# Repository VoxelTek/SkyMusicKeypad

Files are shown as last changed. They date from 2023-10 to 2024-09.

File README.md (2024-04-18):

# Sky Music Keypad
 
A 5x3 grid of MX switches connected to an RP2040-Zero, intended for playing music in the same style as seen in [Sky: Children Of The Light](https://www.thatskygame.com/).



This project was initially created as a birthday present for a friend, but I realised that the community might appreciate this project, and may be able to improve on it in ways I never could.

This device supports MIDI output, keyboard emulation for [Sky Music Nightly](https://specy.github.io/skyMusic), and keyboard emulation for the PC port of Sky.

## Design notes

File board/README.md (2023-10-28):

# SkyMusicPad

A PCB design for a physical replication of the Sky music pad, from Sky: Children Of The Light. 

It uses mechanical keyboard switches for each note, set-up in a matrix arrangement, hooked up to an RP2040-Zero running CircuitPython. MIDI data is outputted over USB to a computer.

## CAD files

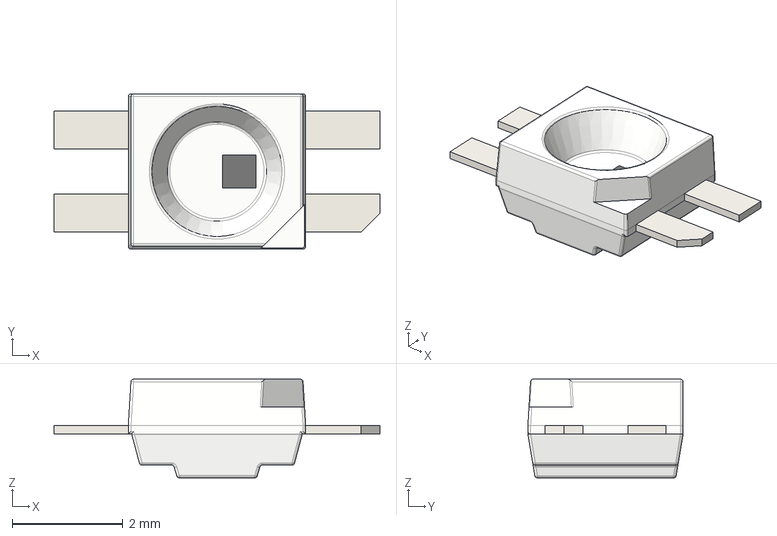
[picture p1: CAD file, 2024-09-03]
board/3D/LED_SK6812MINI-E.step
5.88 x 2.80 x 1.78 mm

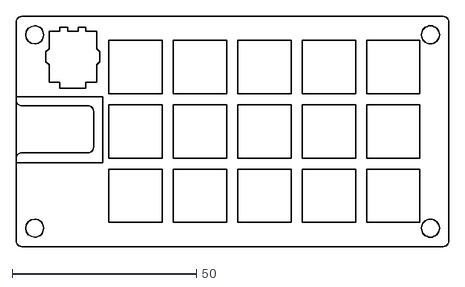
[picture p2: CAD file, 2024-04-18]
board/Outline/SkyMusicPad-brd.dxf
117.5 x 62.5

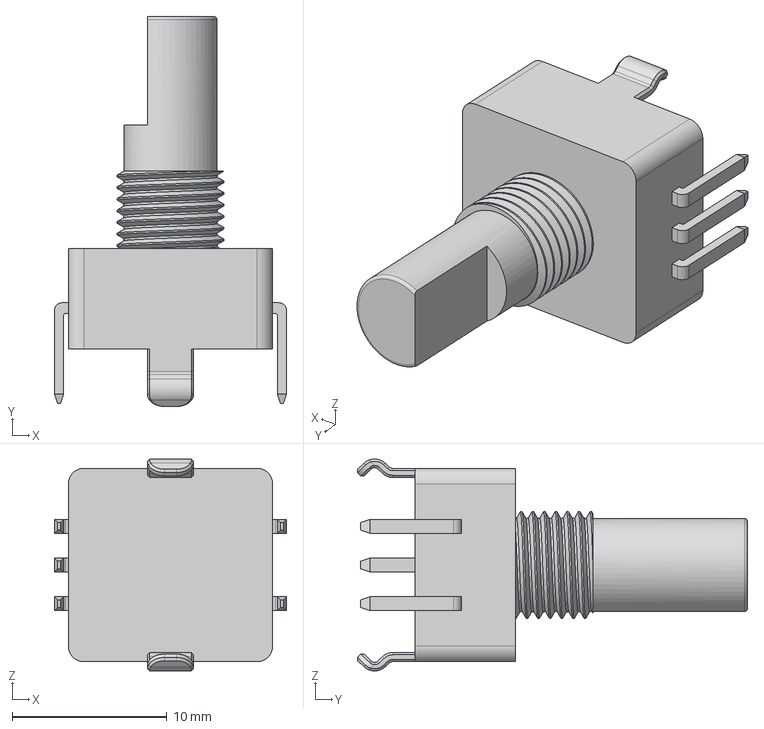
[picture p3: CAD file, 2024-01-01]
board/3D/Rotary Encoder.step
15.0 x 25.2 x 13.7 mm

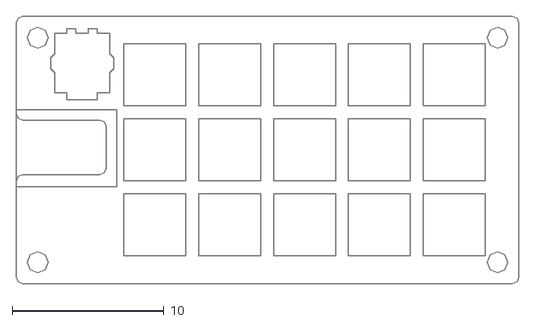
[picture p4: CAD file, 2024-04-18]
board/Outline/SkyMusicPad-brd_2.dxf
33.2 x 17.6

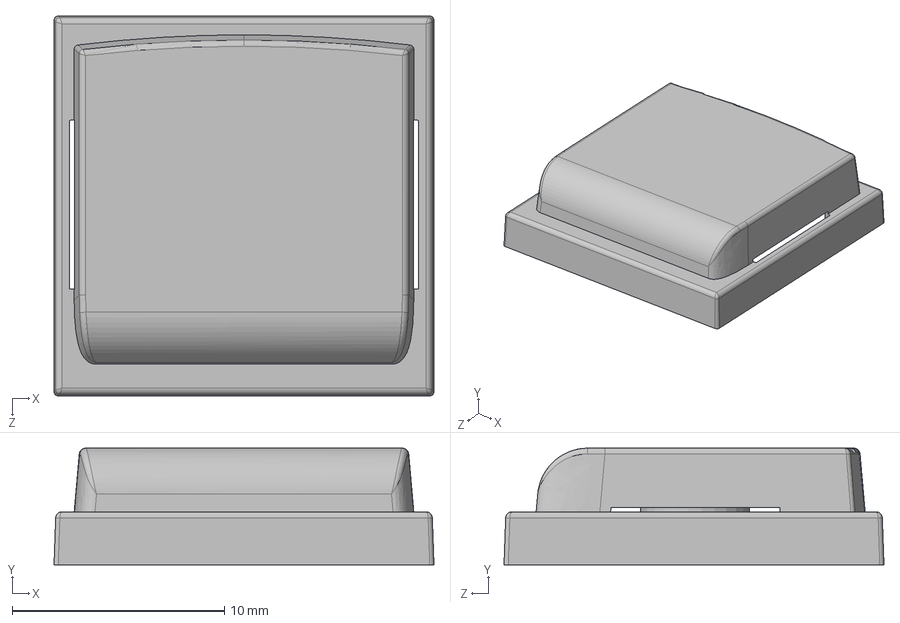
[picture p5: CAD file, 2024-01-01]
board/3D/Key Cap-CHERRY-MX.STEP
17.9 x 5.50 x 17.9 mm

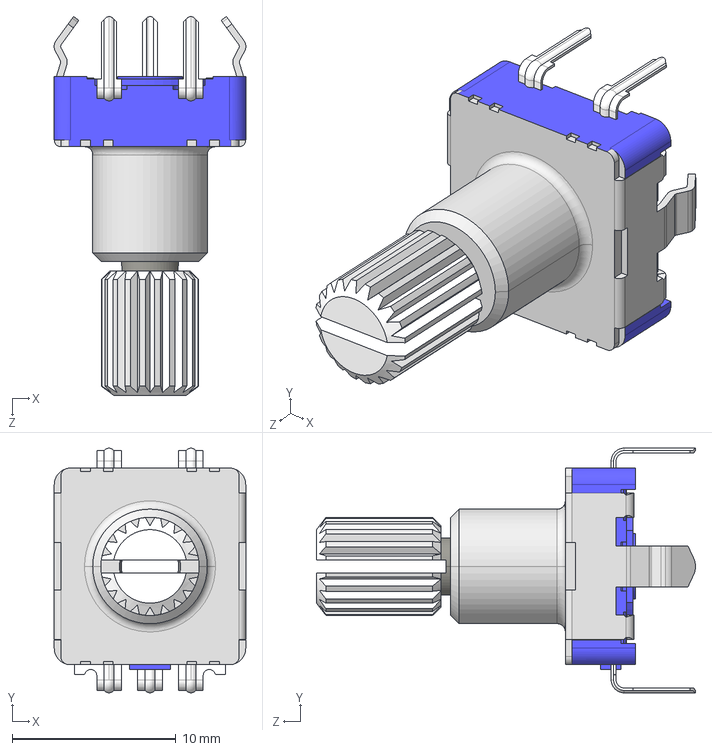
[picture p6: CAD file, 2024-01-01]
board/3D/EC11 Rotary Encoder Dode Switch-15mm .STEP
11.7 x 15.0 x 23.2 mm

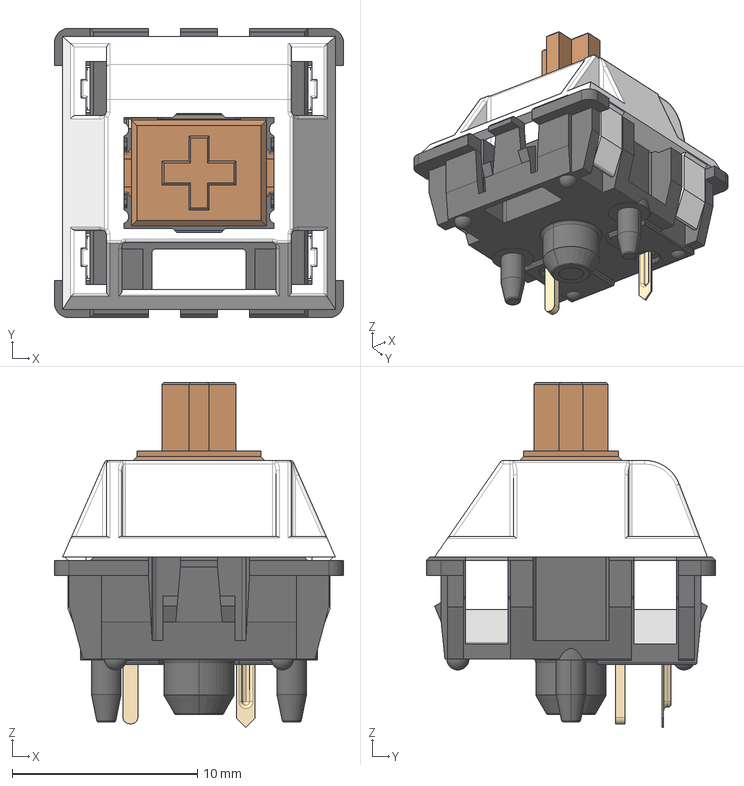
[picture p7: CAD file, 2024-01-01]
board/3D/SW_Cherry_MX_PCB.stp
15.6 x 15.6 x 18.6 mm

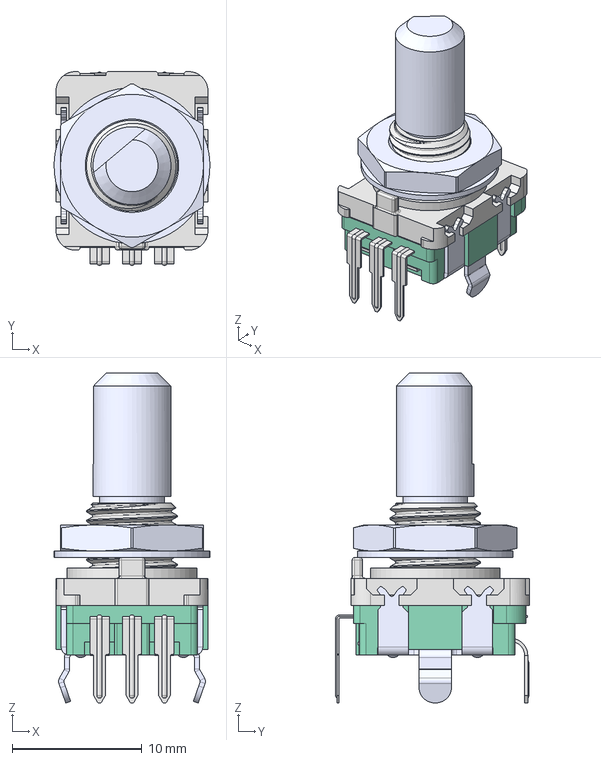
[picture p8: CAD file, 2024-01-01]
board/3D/EC11B-SW-Vert-15F-green.step
12.0 x 14.9 x 25.4 mm

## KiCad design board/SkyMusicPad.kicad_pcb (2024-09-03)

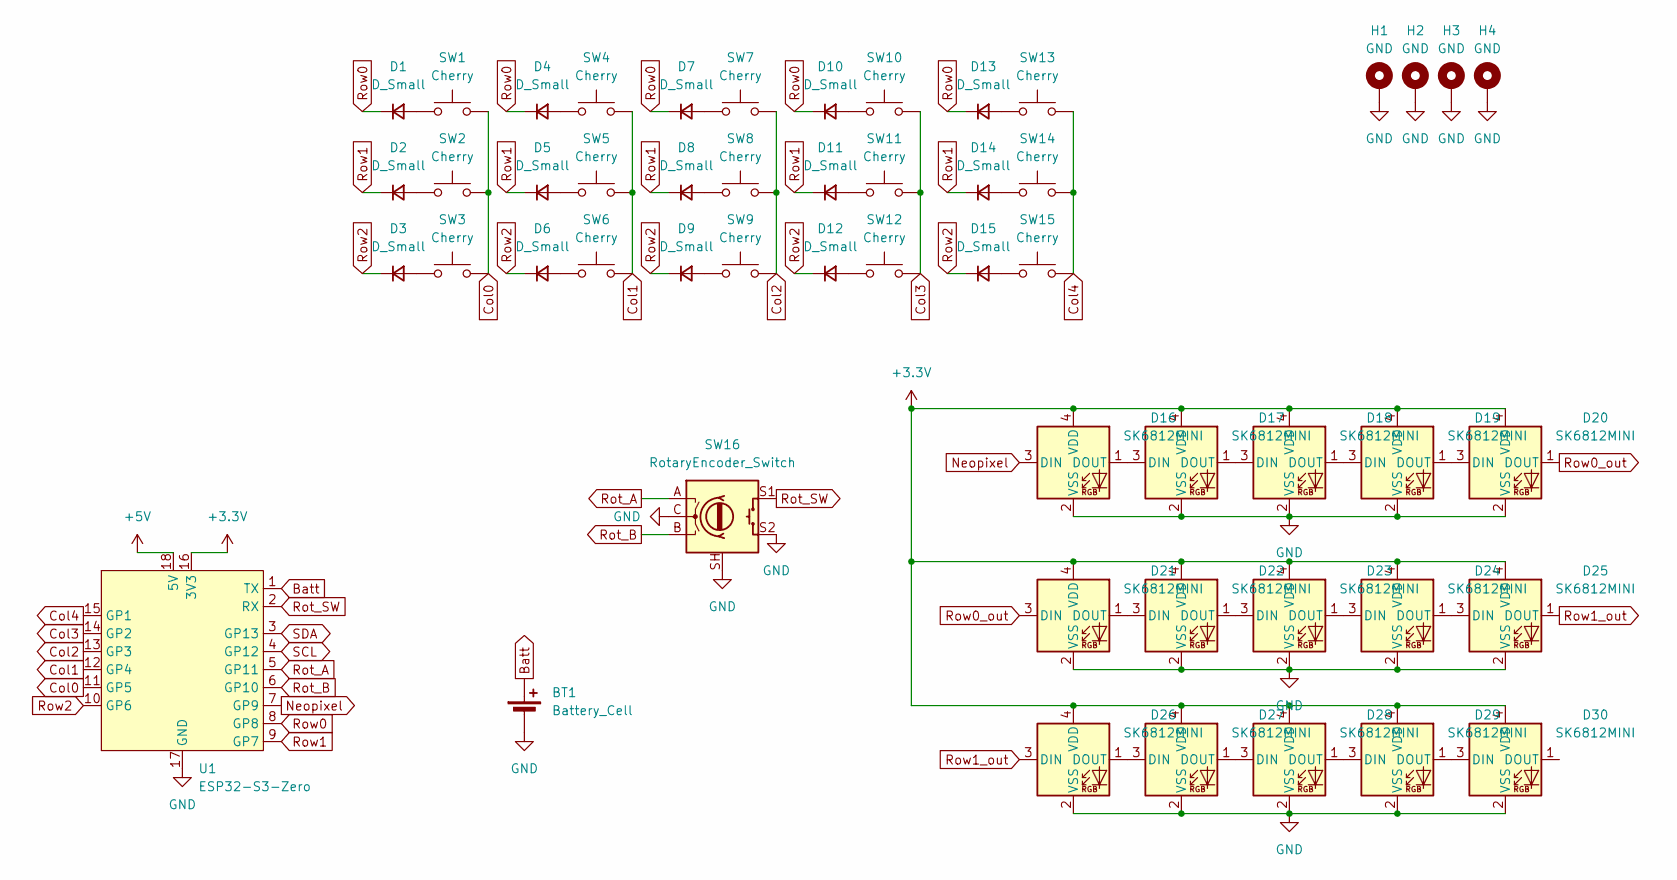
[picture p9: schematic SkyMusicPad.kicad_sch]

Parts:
BT1: Battery_Cell
D1, D2, D3, D4, D5, D6, D7, D8, D9, D10, D11, D12, D13, D14, D15: D_Small; D_0805_2012Metric
D16, D17, D18, D19, D20, D21, D22, D23, D24, D25, D26, D27, D28, D29, D30: SK6812MINI; LED_SK6812MINI_REVERSE
H1, H2, H3, H4: GND; MountingHole_2.2mm_M2_Pad_Via
SW1, SW2, SW3, SW4, SW5, SW6, SW7, SW8, SW9, SW10, SW11, SW12, SW13, SW14, SW15: Cherry; SW_Cherry_MX_PCB
SW16: RotaryEncoder_Switch; RotaryEncoder_Bourns_Vertical_PEC12R-3x17F-Sxxxx
U1: ESP32-S3-Zero

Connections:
+3.3V: D16.4 (VDD), D17.4 (VDD), D18.4 (VDD), D19.4 (VDD), D20.4 (VDD), D21.4 (VDD), D22.4 (VDD), D23.4 (VDD), D24.4 (VDD), D25.4 (VDD), D26.4 (VDD), D27.4 (VDD), D28.4 (VDD), D29.4 (VDD), D30.4 (VDD), U1.16 (3V3)
+5V: U1.18 (5V)
Batt: BT1.1 (+), U1.1 (TX)
Col0: SW1.2, SW2.2, SW3.2, U1.11 (GP5)
Col1: SW4.2, SW5.2, SW6.2, U1.12 (GP4)
Col2: SW7.2, SW8.2, SW9.2, U1.13 (GP3)
Col3: SW10.2, SW11.2, SW12.2, U1.14 (GP2)
Col4: SW13.2, SW14.2, SW15.2, U1.15 (GP1)
GND: BT1.2 (-), D16.2 (VSS), D17.2 (VSS), D18.2 (VSS), D19.2 (VSS), D20.2 (VSS), D21.2 (VSS), D22.2 (VSS), D23.2 (VSS), D24.2 (VSS), D25.2 (VSS), D26.2 (VSS), D27.2 (VSS), D28.2 (VSS), D29.2 (VSS), D30.2 (VSS), H1.1, H2.1, H3.1, H4.1, SW16.C, SW16.S2, SW16.SH (Shell_Ground), U1.17 (GND)
Neopixel: D16.3 (DIN), U1.7 (GP9)
unnamed: D1.2 (A), SW1.1
unnamed: D2.2 (A), SW2.1
unnamed: D3.2 (A), SW3.1
unnamed: D4.2 (A), SW4.1
unnamed: D5.2 (A), SW5.1
unnamed: D6.2 (A), SW6.1
unnamed: D7.2 (A), SW7.1
unnamed: D8.2 (A), SW8.1
unnamed: D9.2 (A), SW9.1
unnamed: D10.2 (A), SW10.1
unnamed: D11.2 (A), SW11.1
unnamed: D12.2 (A), SW12.1
unnamed: D13.2 (A), SW13.1
unnamed: D14.2 (A), SW14.1
unnamed: D15.2 (A), SW15.1
unnamed: D16.1 (DOUT), D17.3 (DIN)
unnamed: D17.1 (DOUT), D18.3 (DIN)
unnamed: D18.1 (DOUT), D19.3 (DIN)
unnamed: D19.1 (DOUT), D20.3 (DIN)
unnamed: D21.1 (DOUT), D22.3 (DIN)
unnamed: D22.1 (DOUT), D23.3 (DIN)
unnamed: D23.1 (DOUT), D24.3 (DIN)
unnamed: D24.1 (DOUT), D25.3 (DIN)
unnamed: D26.1 (DOUT), D27.3 (DIN)
unnamed: D27.1 (DOUT), D28.3 (DIN)
unnamed: D28.1 (DOUT), D29.3 (DIN)
unnamed: D29.1 (DOUT), D30.3 (DIN)
Rot_A: SW16.A, U1.5 (GP11)
Rot_B: SW16.B, U1.6 (GP10)
Rot_SW: SW16.S1, U1.2 (RX)
Row0: D1.1 (K), D4.1 (K), D7.1 (K), D10.1 (K), D13.1 (K), U1.8 (GP8)
Row0_out: D20.1 (DOUT), D21.3 (DIN)
Row1: D2.1 (K), D5.1 (K), D8.1 (K), D11.1 (K), D14.1 (K), U1.9 (GP7)
Row1_out: D25.1 (DOUT), D26.3 (DIN)
Row2: D3.1 (K), D6.1 (K), D9.1 (K), D12.1 (K), D15.1 (K), U1.10 (GP6)
SCL: U1.4 (GP12)
SDA: U1.3 (GP13)

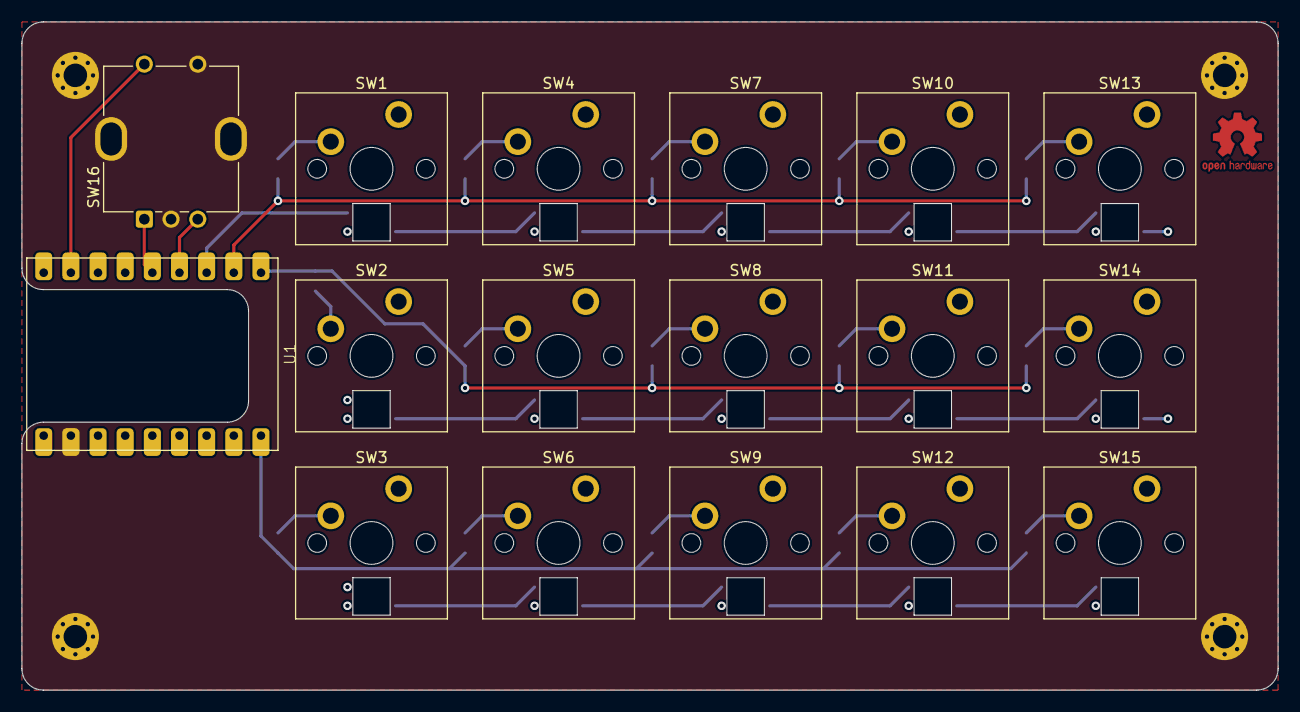
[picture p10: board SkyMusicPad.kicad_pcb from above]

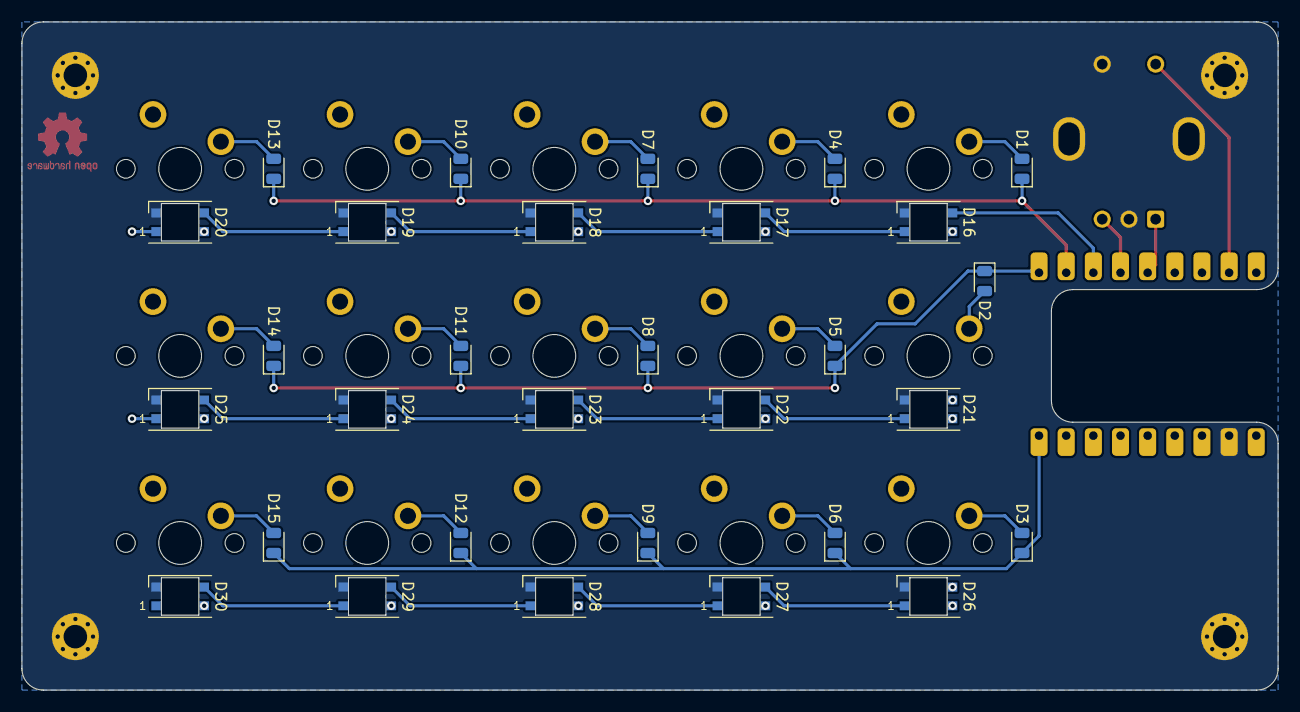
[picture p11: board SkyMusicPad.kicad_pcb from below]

Board: 4 copper layers, 117.5 x 62.5 mm, 51 parts (15 on the bottom side), 43 nets.

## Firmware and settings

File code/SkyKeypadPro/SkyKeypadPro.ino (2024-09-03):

#include <Adafruit_Keypad.h>
#include <Adafruit_Keypad_Ringbuffer.h>

#include "src/ESP32-BLE-Keyboard/BleKeyboard.h"

#include "USBVendor.h"
#include "USB.h"
#include "USBHIDKeyboard.h"
#include "src/USBMIDI/USBMIDI.h"
#include "src/ESP32-BLE-MIDI/src/BLEMidi.h"

#define rotA_pin 11
#define rotB_pin 10
#define rotSW_pin 44


USBVendor usbVendor;

static struct USBHIDKeyboard *usbKeyboard = NULL;
static struct BleKeyboard *bleKeyboard = NULL;

static struct USBMIDI *MIDI = NULL;

#define MIDI_NOTE_C4 60

const byte ROWS = 3;
const byte COLS = 5;

const byte rowPins[ROWS] = {8, 7, 6};
const byte colPins[COLS] = {1, 2, 3, 4, 5};

int counter = 0;

const String deviceName = "Sky Music Keypad";


/*
Mode 0 = Keyboard;
Mode 1 = MIDI;
*/
int mode = 0;


/*
Keymap 0 = Sky Music Nightly (web);
Keymap 1 = In-game playback;
*/
int keymap = 0;


/*
Interface Mode 0: None;
Interface Mode 1: USB;
Interface Mode 2: Bluetooth;
*/
int interface = 0;


bool forceUSB = false;
bool forceBT = false;

bool btEnabled = false;

bool usbStatus = false;

void setup() {
  Serial.begin(115200);
  Serial.println("Starting...");

  pinMode(rotA_pin, INPUT_PULLUP);
  pinMode(rotB_pin, INPUT_PULLUP);

  pinMode(rotSW_pin, INPUT_PULLUP);

  if (mode == 0) {
    static struct USBHIDKeyboard _usbKeyboard;
    usbKeyboard = &_usbKeyboard;
    static struct BleKeyboard _bleKeyboard;
    bleKeyboard = &_bleKeyboard;
  }
  else if (mode == 1) {
    static struct USBMIDI _MIDI;
    MIDI = &_MIDI;
  }

  if (!forceBT) {         // Initialise USB
    usbInit();
  }
  else if (!forceUSB) {   // Initialise BT
    btInit();
  }

}

void loop() {
  setMode();
  if (interface == 2) {
    sendBattery();
  }
}


void sendBattery() {
  if (mode == 0) {

  }
  else if (mode == 1) {

  }
}


void usbInit() {
  if (mode == 0) {
    usbKeyboard->begin();
    USB.begin();
  }
  else if (mode == 1) {

  }
}

void btInit() {
  if (mode == 0) {
    bleKeyboard->setName(deviceName);
    bleKeyboard->begin();
  }
  else if (mode == 1) {
    BLEMidiServer.begin(deviceName);
  }
  btEnabled = true;
}


void switchToUSB() {
  if (interface != 1) {
    if ((interface == 2) || (btEnabled)) {
        if (mode == 0) {
          bleKeyboard->stopAdvertising();
        }
        else if (mode == 1) {
          
        }
    }
  }
}

void switchToBT() {

}




void setMode() {
  if (!(forceUSB || forceBT)) {
    usbStatus = usbVendor.mounted();
    if (usbStatus) {            // Is USB connected?
      switchToUSB();
      return;
    }
    else {                      // Not connected to USB
      switchToBT();
      if (bleKeyboard->isConnected()) {  // Bluetooth device connected!
        interface = 2;
      }
      else {                    // No BT or USB connection
        interface = 0;
      }
    }
  }
}

void sendKey(uint8_t key, bool press = true) {
  if (interface == 0) {
    return;
  }
  else if (interface == 1) {
    if (press) {
      usbKeyboard->press(key);
    }
    else {
      usbKeyboard->release(key);
    }
  }
  else if (interface == 2) {
    if (press) {
      bleKeyboard->press(key);
    }
    else {
      bleKeyboard->release(key);
    }
  }
}






/*
TODO: mostly everything
- add battery level (line 101 in BleKeyboard.cpp)
- add matrix (use hex for keys?)
*/

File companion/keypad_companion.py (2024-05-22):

import sys
import webbrowser
import companion_assets_rc
from PyQt6 import QtWidgets, uic

import serial
from serial.tools import list_ports

Ui_MainWindow1, QtBaseClass1 = uic.loadUiType("KeypadCompanion.ui")


class KeypadCompanion(QtWidgets.QMainWindow, Ui_MainWindow1):
    def __init__(self):
        QtWidgets.QMainWindow.__init__(self)
        Ui_MainWindow1.__init__(self)
        self.setupUi(self)

        self.setFixedSize(600, 400)

        self.buttonBox.accepted.connect(self.accept)
        self.buttonBox.rejected.connect(self.reject)
        self.buttonBox.helpRequested.connect(self.help)
        self.buttonBox.button(QtWidgets.QDialogButtonBox.StandardButton.Save).clicked.connect(self.save)
    
    def accept(self):
        self.pushSettings()
        self.close()
    def reject(self):
        self.close()

    def help(self):
        webbrowser.open("https://github.com/VoxelTek/SkyMusicKeypad/wiki", new=2)

    def save(self):
        pass

    def pushSettings(self):
        pass
 


def get_ports():
    port = list(list_ports.comports())
    for p in port:
        print(p.device)

if __name__ == "__main__":
    get_ports()
    app = QtWidgets.QApplication(sys.argv)
    window = KeypadCompanion()
    window.show()

    sys.exit(app.exec()) 

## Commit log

2023-10-31 Adjusted rotary encoder to have common point GND
    [SkyMusicPad-B_Cu.gbr, SkyMusicPad-B_Mask.gbr, SkyMusicPad-B_Paste.gbr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]
2023-10-31 Clean-up of code, add button to reset encoder
2023-11-01 KiCad backup update, has no relevance.
2023-11-01 Fixed the use of the incorrect footprint for MX
    [SkyMusicPad.kicad_pcb, SkyMusicPad.kicad_sch]
2023-11-16 Updated the code to support keyboard output
    Modified the code so that now it can optionally output a keyboard button signal instead of just MIDI.
2024-01-11 File system cleanup
    [SkyMusicPad.kicad_pcb]
2024-04-16 misc changes
    [SkyMusicPad.kicad_pcb, SkyMusicPad.kicad_sch]
2024-04-17 Redesign, sorta
    [SkyMusicPad.kicad_pcb]
2024-04-18 Add outline, for use with 3D CAD
    [SkyMusicPad-brd.dxf, SkyMusicPad-brd_2.dxf]
2024-04-19 Gerber regeneration
    [SkyMusicPad-B_Cu.gbr, SkyMusicPad-B_Mask.gbr, SkyMusicPad-B_Paste.gbr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]
2024-04-23 Create PCB LICENSE
2024-05-19 Hardware changes, 3D regen
    [SkyMusicPad.kicad_pcb]
2024-07-14 Change global net shapes, move encoder position
    [SkyMusicPad.kicad_pcb, SkyMusicPad.kicad_sch]
2024-08-28 Add submodule, begin ESP32-S3-Zero development
2024-08-28 Code migration
    - Remove CircuitPython code
    - Begin Arduino code development
    - Add patched BLE Keyboard library
    [SkyMusicPad.kicad_sch]
2024-08-28 Fix submodule, remove PCB lock
2024-08-28 Fix code to match relocated submodule
    [SkyKeypadPro.ino]
2024-08-29 Code and PCB updates
    [SkyMusicPad.kicad_sch]
2024-08-29 Update ESP32-BLE-Keyboard
2024-08-29 Remove ESP32-BLE-Keyboard submodule
    Currently in the process of fixing up submodules.
2024-08-29 I hate C++. With a burning passion.
    [SkyKeypadPro.ino]
2024-09-02 Further board and code development.
    [SkyMusicPad.kicad_pcb, SkyMusicPad.kicad_sch]
2024-09-03 Fix and add LEDs
    [LED_SK6812MINI-E.step, SkyMusicPad.kicad_pcb, SkyMusicPad.kicad_sch]
